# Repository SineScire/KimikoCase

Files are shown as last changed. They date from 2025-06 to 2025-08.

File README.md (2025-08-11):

<a href="https://github.com/SineScire/KimikoCase">KimikoCase</a> © 2025 by <a href="https://github.com/SineScire">SineNomen</a> is licensed under <a href="https://creativecommons.org/licenses/by-nc-sa/4.0/">CC BY-NC-SA 4.0</a>

# KimikoCase
A tented case for the [Kimiko Rev 2](https://github.com/Keycapsss/Kimiko) with a gasket mount switchplate design

There are multiple versions of the gaskets:
* Soft: Switchplate flexes with the press of a single key
* Medium: Switchplate flexes with the press of multiple keys
* Hard: Switchplate hardly flexes with the press of multiple keys

Read the manual here

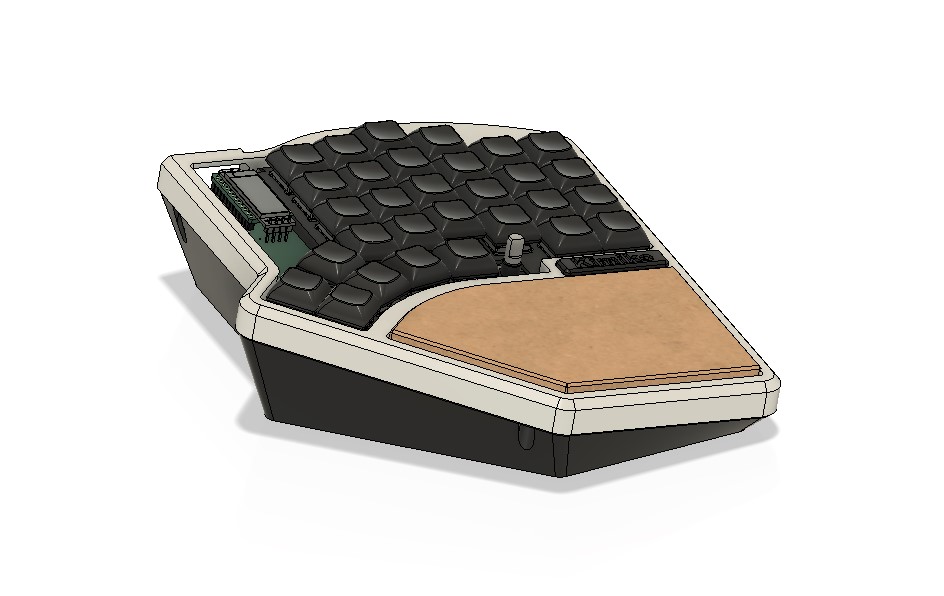
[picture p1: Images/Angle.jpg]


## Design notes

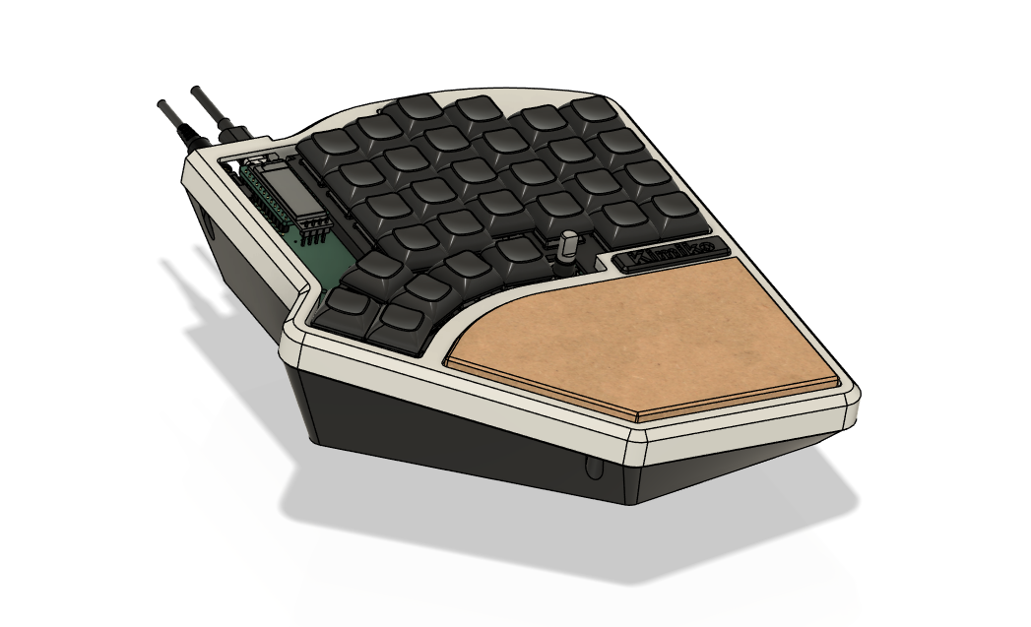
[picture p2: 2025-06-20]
Images/KimikoCase.png

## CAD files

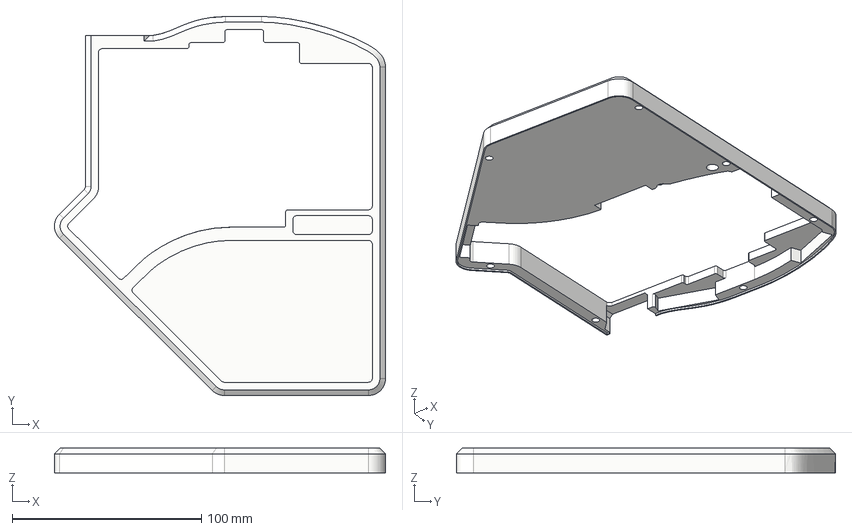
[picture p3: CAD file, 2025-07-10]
Files/TopHousing.step
175.1 x 200.4 x 13.0 mm

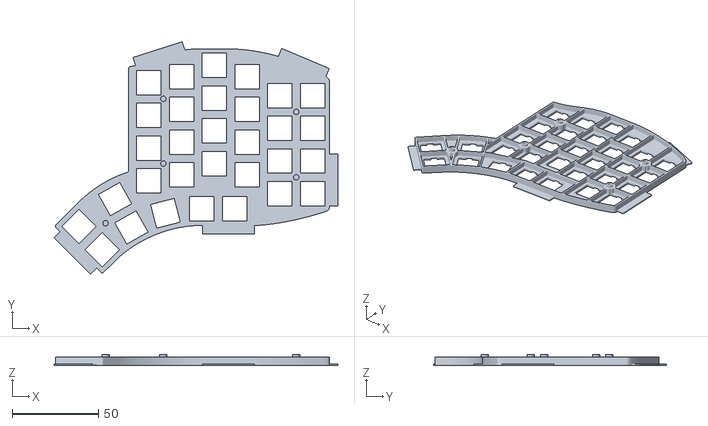
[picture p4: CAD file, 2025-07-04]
Files/SwitchPlateL.stl
164.9 x 135.0 x 6.50

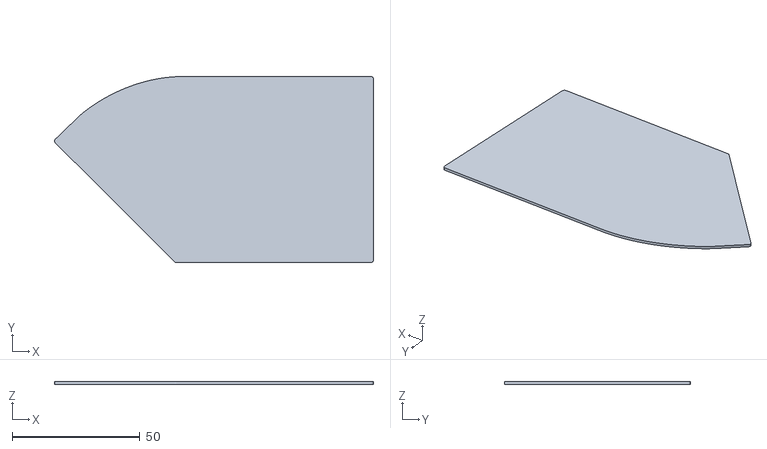
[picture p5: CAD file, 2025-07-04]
Files/Template.stl
125.1 x 73.0 x 1.00

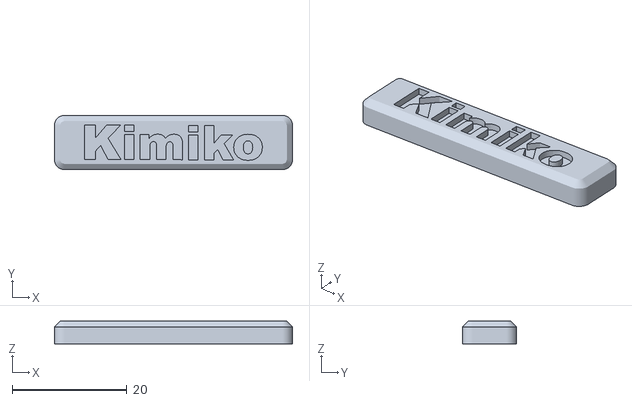
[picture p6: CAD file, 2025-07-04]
Files/TagPlate.stl
41.4 x 9.40 x 4.00

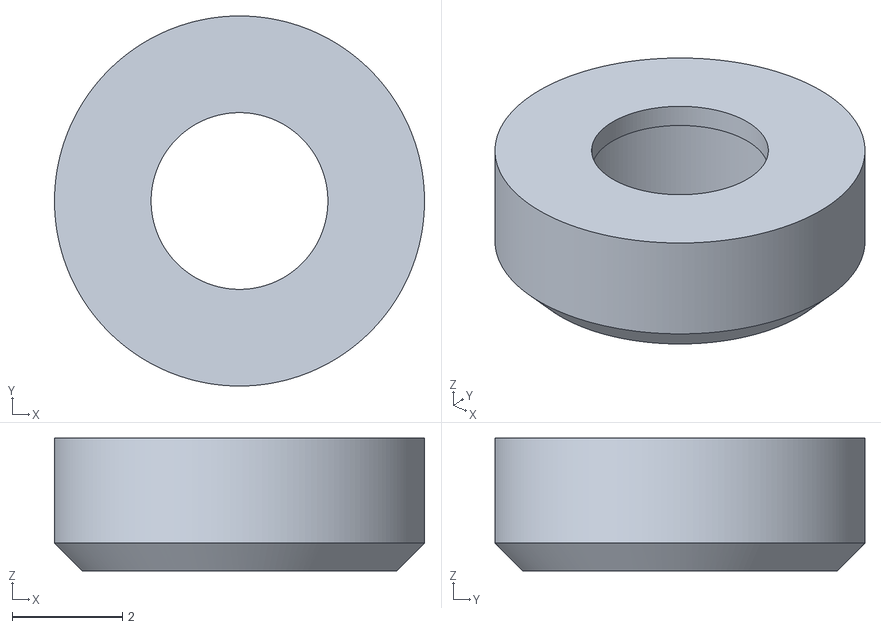
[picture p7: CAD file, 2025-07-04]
Files/Washer.stl
6.70 x 6.70 x 2.40

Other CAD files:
Files/TopHousingR.stl
Files/TopHousingL.stl
Files/SwitchPlateR.stl

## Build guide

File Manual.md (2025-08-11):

## BOM
* For a set of two complete cases

| Part | Quantity | Description |
| ---- | --- | --- |
| Top Housing | 2x | 3D Printed mirrored parts |
| Bottom Housing | 2x | 3D Printed mirrored parts |
| Switchplate | 2x | 3D Printed mirrored parts |
| Gasket | 10x | 3D Printed part with flexible filament with a hardness around 95A |
| Washer | 10x | 3D Printed part |
| Tag Plate | 2x | 3D Printed part |
| Template | 1x | 3D Printed template to help cut out the wrist rest material |
| m3x6mm Socket Head Screws | 14x | To fasten the top and bottom housing |
| m2x5mm Socket Head Screws | 10x | To fasten the switchplate to the PCB |
| m3x4mm Threaded Insert | 14x | Brass inserts for the top housing |
| m2x4mm Threaded Insert | 10x | Brass inserts for the switchplate |
| Kimiko PCB | 2x | The PCB for each side for inserting the Brass Inserts |
| Wrist Rest material | 2x | 5mm thick material of atleast 130mm x 80mm |
| Stick on Rubber Feet | 10x | Rubber feet with a diameter of 15mm and 2mm thickness |
| Double Sided Tape | 1x | To adhere the wristrest and tagplate |
| Soldering Iron | 1x | To press in the brass inserts |

## 1. Printing the parts
* The gasket is printed with a flexible type of filament with a hardness around 95A
* Suggested printing orientations for the parts with supports enabled, showing right hand side case only.

| Top housing | Bottom housing | Switchplate |
| --- | --- | --- |
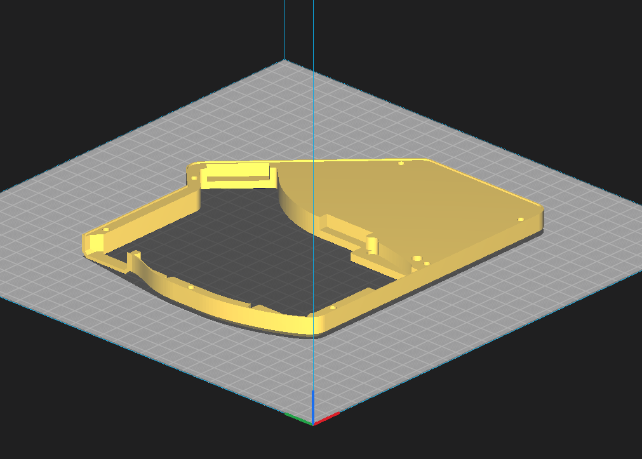
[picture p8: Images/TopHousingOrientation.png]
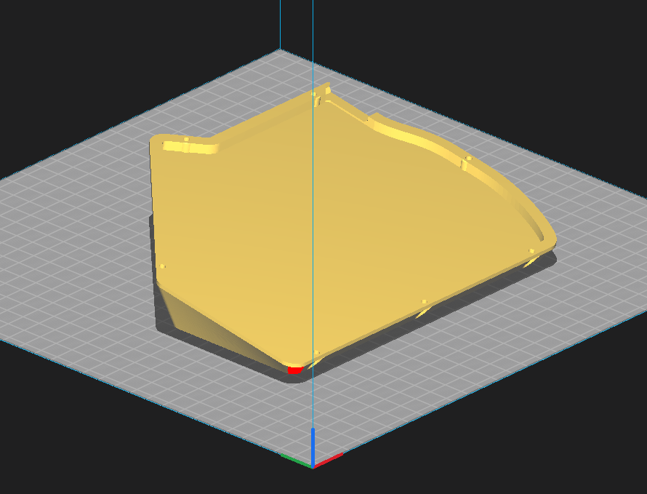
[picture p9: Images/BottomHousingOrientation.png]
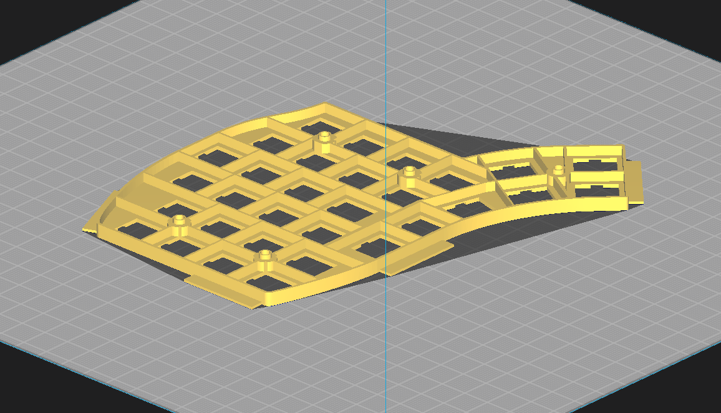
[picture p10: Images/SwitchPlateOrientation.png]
|  |  |  |

| Washer | Tag plate | Gasket |
| --- | --- | --- |
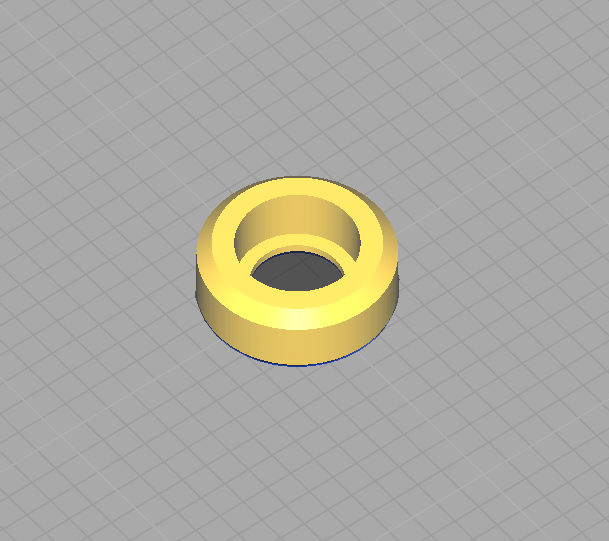
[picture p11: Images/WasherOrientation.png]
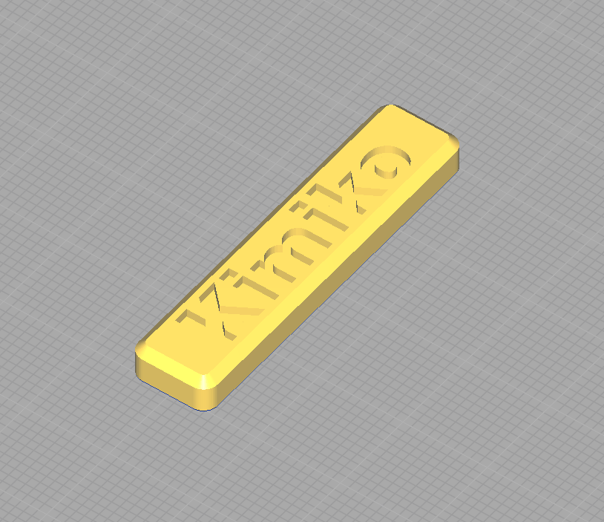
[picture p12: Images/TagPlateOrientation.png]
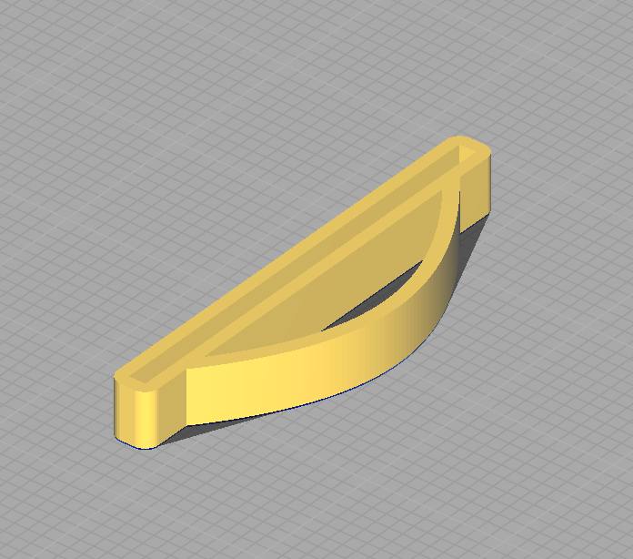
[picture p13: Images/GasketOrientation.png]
|  |  |  |

## 2. Assembling the case
### Preparing the Switchplate
* Parts needed: Switchplate, PCB, m2x4mm Threaded inserts, m2x5mm Socket Head Screws, Washers, Gaskets
1. Place the switchplate with the standoffs facing up in the same suggested orientation it was printed in and place the PCB onto the switchplate as shown in the image below.
2. Using a soldering iron, insert the five m2x4mm threaded inserts into the switchplate at the blue highlighted spots in the image below.

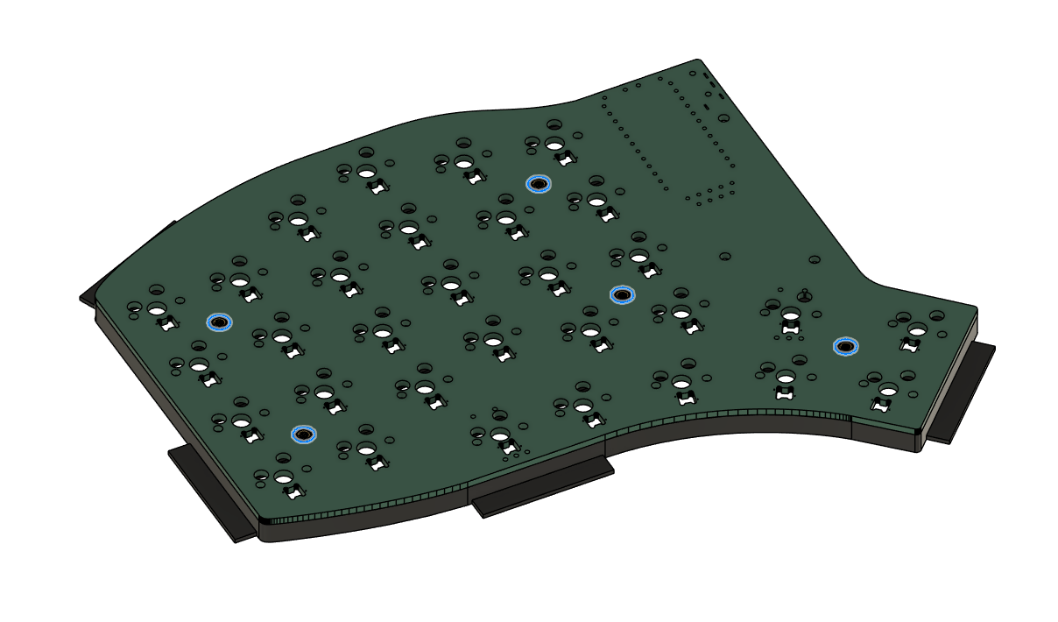
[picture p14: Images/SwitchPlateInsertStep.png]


3. After the inserts have cooled down, fasten the m2x5mm socket head screws with the washer as shown in the image below.

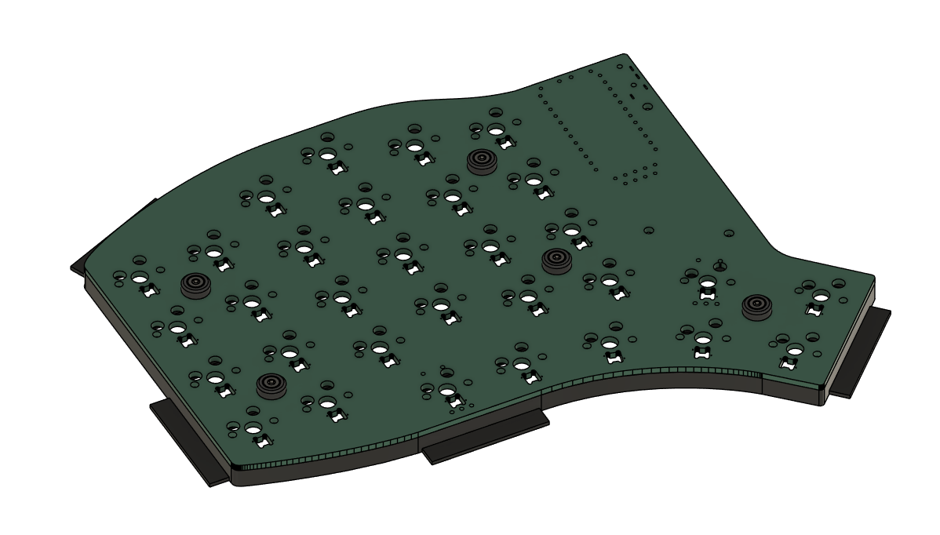
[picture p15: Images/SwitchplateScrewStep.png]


4. Place your gaskets of choice on the switchplate and assemble the PCB/Switchplate further with the controller and switches/keycaps of choice as shown in the image below.

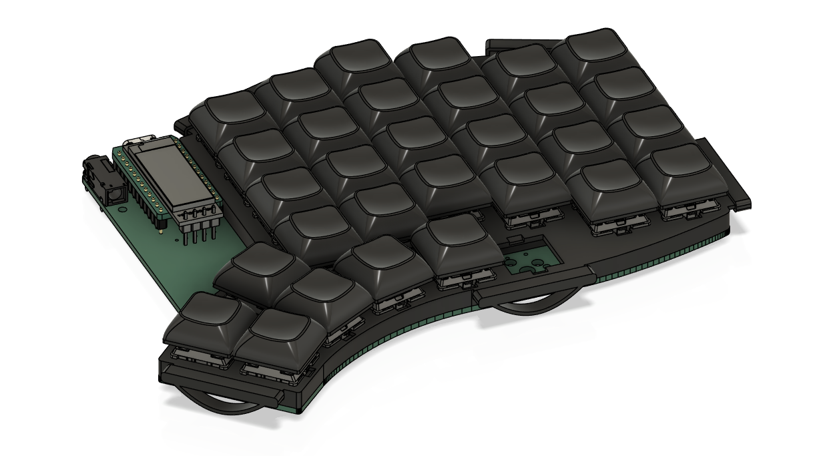
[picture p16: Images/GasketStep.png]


### Preparing the Top Housing
* Parts needed: Top housing, m3x4mm Threaded Inserts, Template, Wrist Rest material, Tag Plate, Double Sided Tape
1. Place the tophousing face down and use a soldering iron to insert the seven m3x4mm threaded inserts at the blue highlighted spots in the image below.

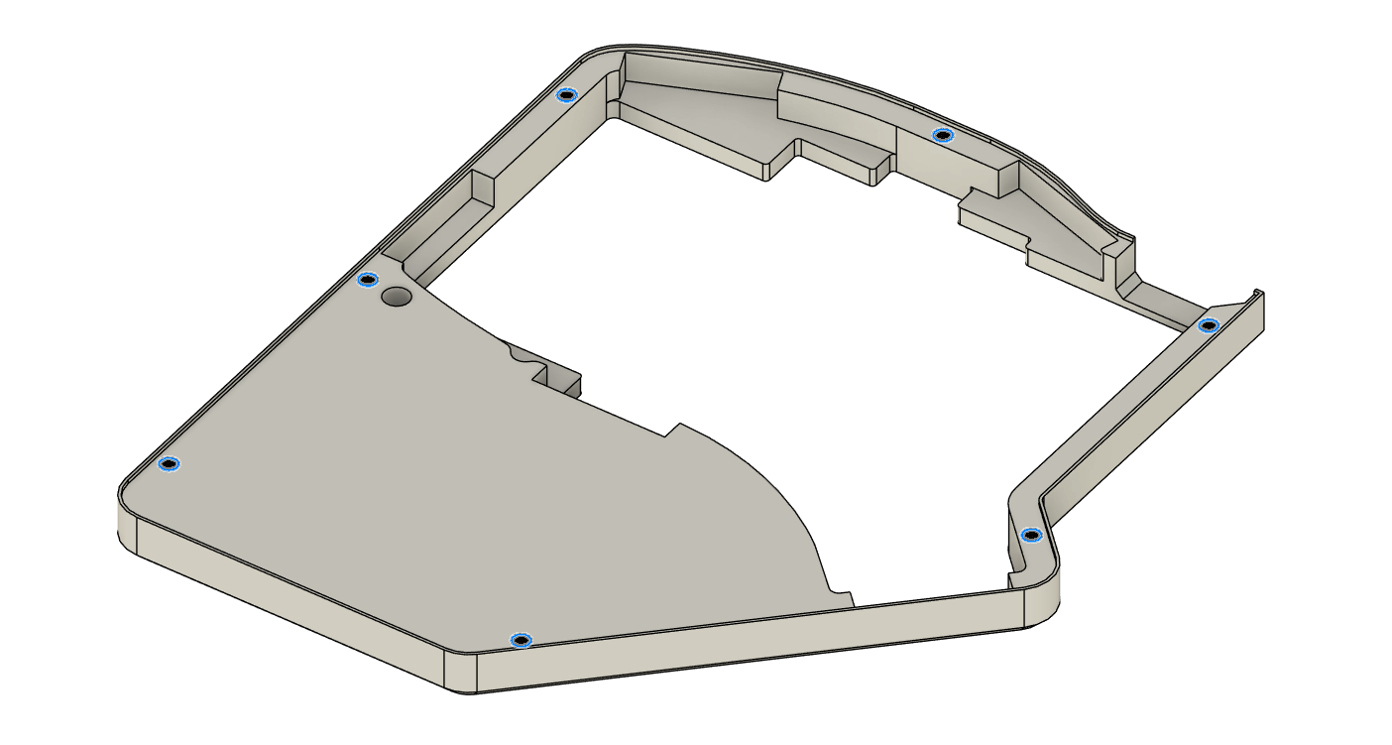
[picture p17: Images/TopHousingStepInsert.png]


2. Using the template, cutout the wristrest from the wristrest material as shown in the image below.

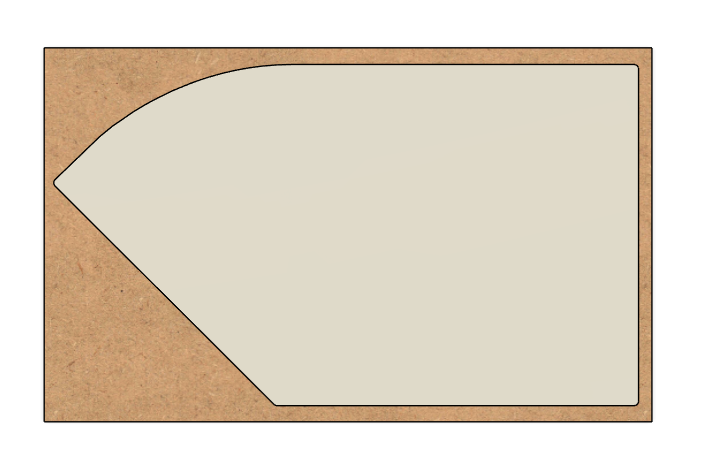
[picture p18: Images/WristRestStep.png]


3. With doublesided tape the wristrest material and the tag plate can be placed on the top housing.

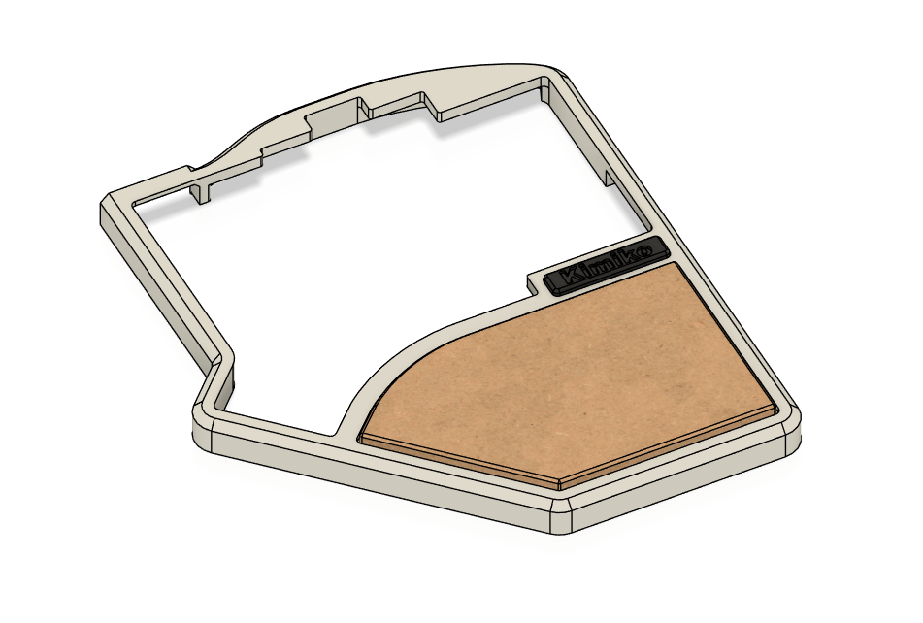
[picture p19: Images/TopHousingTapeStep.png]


### Preparing the Bottom Housing and assembling the case
* Parts needed: Bottom Housing, Stick on Feet, Top Housing, Assembled switchplate/PCB
1. Place the five stick on feet underneath the bottom housing. If you only have four stick on feet available for each side, skip the spot underneath the thumb cluster.
2. The case can now be assembled, place the switchplate with the gaskets on the bottom housing and while aligning the top housing, lower it in place. Use seven m3x5mm Socket Head Screws to fasten the top housing to the bottom housing. The case is now complete!



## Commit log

2025-06-20 Create Manual.md
    Added BOM
2025-06-20 Update Manual.md
    Added printing orientations
